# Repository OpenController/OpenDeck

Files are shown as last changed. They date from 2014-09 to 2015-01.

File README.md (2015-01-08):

# OpenDeck Platform

OpenDeck MIDI platform is a combination of microcontroller firmware, PCB board and GUI application.
The platform allows hassle-free building of MIDI controllers and their configuration via MIDI System Exclusive messages,
without any need of reprogramming the chip.

This repository contains MCU code, part list, schematic (circuit and PCB) and pre-compiled binaries, available for serial
baud rates: 38400, for use with virtual MIDI cable software and serial-to-midi converter, and 31250 for use with native
MIDI.

Code base is built upon OpenDeck library, Ownduino library (minimal fork of Arduino core library)
and modified Arduino MIDI library 3.2. All code is available under GNU GPL v3 licence.

# Configurable features

## Hardware parameters

* Board type (OpenDeck reference board, Tannin board, or user-defineable board in `HardwareControl.cpp`)
* Enable/disable buttons
* Enable/disable LEDs
* Enable/disable potentiometers

## Features

### MIDI features

* Enable/disable standard note off

### Button features

* Enable/disable long-press mode

### LED features

* Enable/disable start-up routine
* Enable/disable blinking

### Potentiometer features

* Enable/disable potentiometer notes

### MIDI channels

* Button note channel
* Long-press button note channel
* Program change button channel
* Potentiometer CC channel
* Potentiometer program change channel
* Potentiometer note channel
* Input MIDI channel

## Button configuration

* Hardware parameters: long-press time
* Button type (momentary/latching)
* Enable/disable program change send instead of notes
* Button MIDI note

## Potentiometer configuration

* Hardware parameters: (reserved/no parameters yet)
* Enable/disable potentiometer
* Enable/disable program change send instead of CC
* Invert potentiometer
* CC/Program change number
* Lower CC/PP limit
* Upper CC/PP limit

## LED configuration

* Hardware parameters: total LED number, blink time, start-up switch time, start-up routine
* LED activation note
* LED start-up number
* Test LED state (constant on/off, blink on/off)

## Data restoration

* Restoration of single parameter back to default (ie. restore potentiometer 6 CC number to default)
* Restoration of all parameters within message type (ie. restore all button notes to default)
* Complete factory reset of all values

# SysEx configuration

All configuration is done using MIDI System Exclusive messages.
Before attempting to change parameters of OpenDeck controller, a "Hello World" message must be sent to controller:

F0 00 53 43 F7

F0 is a SysEx start, 00, 50 and 43 are ID bytes, and F7 is SysEx end. After the controller receives the message, it
enables full manipulation using SysEx protocol, and responds with the same message, with an extra ACK byte at the end, 0x41:

F0 00 53 43 41 F7

After that, board type must be specified. When using OpenDeck reference board, set it using the following message:

F0 00 53 43 01 00 00 00 00 01 F7

Each SysEx message (except for hello world) uses the same format:

F0 ID ID ID WISH AMOUNT MESSAGE_TYPE MESSAGE_SUBTYPE PARAMETER_ID NEW_PARAMETER_ID F7

## ID

* Byte 1: 0x00
* Byte 2: 0x53
* Byte 3: 0x43

## WISH

* Get (0x00)
Used to request data from the controller
* Set (0x01)
Changing parameters
* Restore (0x02)
Data restoration to default state

## AMOUNT
* Single (0x00)
Only one parameter
* All (0x01)
All parameters

### MESSAGE_TYPE
There's a total of 7 message types available.

* Hardware configuration (0x00)
* Features (0x01)
* MIDI channel (0x02)
* Button (0x03)
* Potentiometer (0x04)
* LED (0x05)
* All (0x07)

### MESSAGE_SUBTYPE

Features, buttons, potentiometers, LEDs are the only types of message which have a sub-type. When dealing
with other message types, code 0x00 must be specified as sub-type.

Features:

* MIDI features (0x00)
* Button features (0x01)
* LED features (0x02)
* Potentiometer features (0x03)

Buttons:
* Hardware parameter (0x00)
* Type (0x01)
* Program change enabled (0x02)
* Button note (0x03)

Potentiometers:
* Hardware parameter (0x00)
* Pot enabled (0x01)
* Program change enabled (0x02)
* Pot inverted (0x03)
* CC/PP number (0x04)
* Lower CC/PP limit (0x05)
* Upper CC/PP limit (0x06)

LEDs:
* Hardware parameter (0x00)
* Activation note (0x01)
* Start-up number (0x02)
* State (0x03)

For more information, see examples in /examples folder.

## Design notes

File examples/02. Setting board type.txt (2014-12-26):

Controller doesn't work until board type has been specified.

For OpenDeck reference board, board type is 01:
F0 00 53 43 01 00 00 00 00 01 F7

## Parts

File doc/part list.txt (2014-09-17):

# OpenDeck reference board:

1x  reference PCB
1x  Arduino Pro Mini
1x  ULN2803 Darlington transistor array
1x  74HC238 decoder
2x  4051 analogue multiplexer
4x  220 Ohm resistors
32x 1N4148 diodes
1x  10µF electrolytic cap
5x  0.1µF capacitors

# USB MIDI board

1x  USB MIDI PCB
1x  Altmustech AU-123 Integrated USB MIDI Controller
1x  USB B female connector
1x  10µF electrolytic cap
1x  0.1µF cap
1x  0.01µF cap
2x  22p caps
2x  3mm LEDs
2x  330 Ohm resistors
1x  2k2 Ohm resistor
1x  1kOhm resistor
1x  12Mhz crystal
1x  2n2222 transistor

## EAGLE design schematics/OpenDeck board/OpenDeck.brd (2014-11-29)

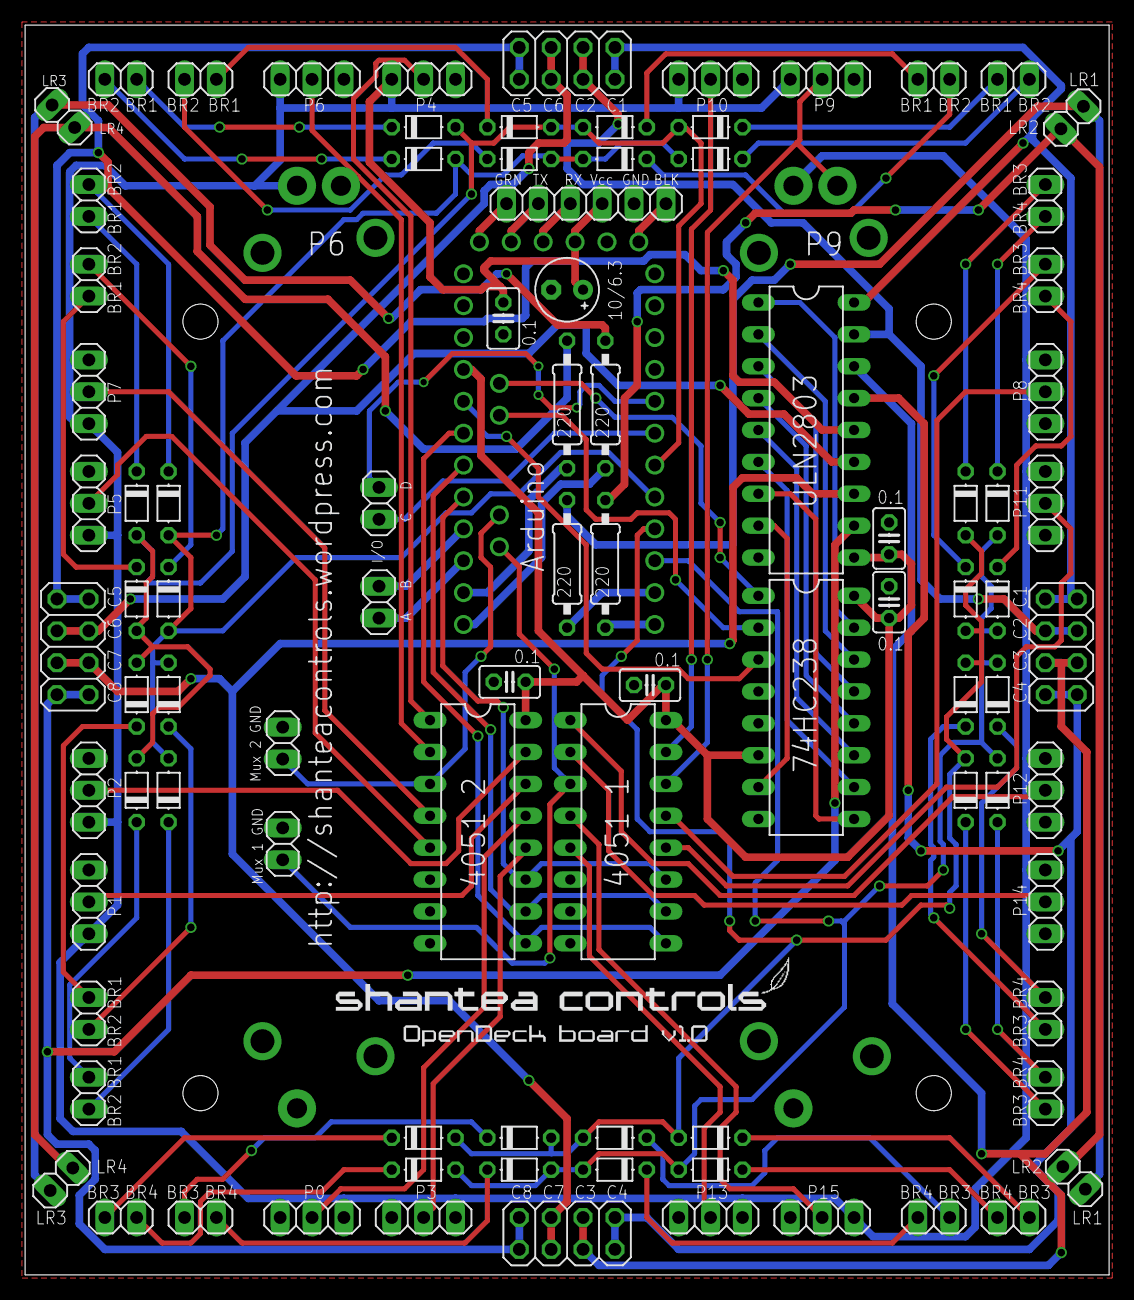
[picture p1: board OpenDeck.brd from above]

Board: 2 copper layers, 86.4 x 99.6 mm, 92 parts (1 on the bottom side), 95 nets.

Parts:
E$1: ARDUINO_PRO_MINI
E$2, E$3, E$7, E$11, E$14, E$18, E$22, E$35, E$41, E$42, E$43, E$46, E$47, E$62, E$64, E$73, E$74, E$82, E$87, E$88, E$94, E$95, E$96, E$97: 1X02
E$4, E$32, E$33, E$81: 0207/10
E$5: E2,5-5
E$6, E$9, E$20, E$63: 2X04
E$8, E$48, E$51, E$52, E$53, E$54, E$59, E$60, E$61, E$75, E$76, E$77, E$78, E$98, E$100, E$101: 1X03
E$10, E$12, E$16, E$17, E$19, E$21, E$23, E$24, E$25, E$26, E$27, E$28, E$29, E$30, E$31, E$34, E$36, E$37, E$38, E$39, E$40, E$44, E$45, E$65, E$66, E$67, E$68, E$69, E$70, E$71, E$72, E$92: D-5
E$13, E$49, E$84: DIL16
E$15, E$50, E$85, E$86, E$89: C025-025X050
E$80: DIL18
E$83: 1X06

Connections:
B_ROW_1: E$1.7, E$12.A, E$17.A, E$21.A, E$24.A, E$66.A, E$68.A, E$70.A, E$72.A
B_ROW_2: E$1.8, E$10.A, E$16.A, E$19.A, E$23.A, E$65.A, E$67.A, E$69.A, E$71.A
B_ROW_3: E$1.9, E$27.A, E$28.A, E$30.A, E$34.A, E$38.A, E$39.A, E$44.A, E$92.A
B_ROW_4: E$1.10, E$25.A, E$26.A, E$29.A, E$31.A, E$36.A, E$37.A, E$40.A, E$45.A
COLUMN_1: E$9.7, E$9.8, E$20.7, E$20.8, E$80.18
COLUMN_2: E$9.5, E$9.6, E$20.5, E$20.6, E$80.17
COLUMN_3: E$6.5, E$6.6, E$9.3, E$9.4, E$80.16
COLUMN_4: E$6.7, E$6.8, E$9.1, E$9.2, E$80.15
COLUMN_5: E$20.1, E$20.2, E$63.7, E$63.8, E$80.14
COLUMN_6: E$20.3, E$20.4, E$63.5, E$63.6, E$80.13
COLUMN_7: E$6.3, E$6.4, E$63.3, E$63.4, E$80.12
COLUMN_8: E$6.1, E$6.2, E$63.1, E$63.2, E$80.11
DEC_0: E$1.A5, E$84.1
DEC_1: E$1.A4, E$84.2
DEC_2: E$1.20, E$84.3
DEC_OUT_0: E$80.1, E$84.15
DEC_OUT_1: E$80.2, E$84.14
DEC_OUT_2: E$80.3, E$84.13
DEC_OUT_3: E$80.4, E$84.12
DEC_OUT_4: E$80.5, E$84.11
DEC_OUT_5: E$80.6, E$84.10
DEC_OUT_6: E$80.7, E$84.9
DEC_OUT_7: E$80.8, E$84.7
GND: E$1.4, E$1.23, E$1.GND, E$5.-, E$8.3, E$13.6, E$13.7, E$13.8, E$15.2, E$48.1, E$49.6, E$49.7, E$49.8, E$50.2, E$51.1, E$52.1, E$53.1, E$54.1, E$59.1, E$60.1, E$61.1, E$75.1, E$76.1, E$77.1, E$78.1, E$80.9, E$83.5, E$84.4, E$84.5, E$84.8, E$85.1, E$86.1, E$87.2, E$88.2, E$89.2, E$98.3, E$100.3, E$101.3
LED_ROW_1: E$18.1, E$33.2, E$82.1
LED_ROW_2: E$18.2, E$32.2, E$82.2
LED_ROW_3: E$4.2, E$22.2, E$41.2
LED_ROW_4: E$22.1, E$41.1, E$81.2
MUX_1_OUT: E$1.A7, E$49.3, E$88.1
MUX_2_OUT: E$1.A6, E$13.3, E$87.1
P0A: E$48.2, E$49.13
P1: E$13.13, E$101.2
P1A: E$49.14, E$54.2
P2: E$13.14, E$75.2
P2A: E$49.15, E$53.2
P3: E$13.15, E$76.2
P3A: E$49.12, E$59.2
P4: E$13.12, E$100.2
P4A: E$49.1, E$77.2
P5: E$8.2, E$13.1
P5A: E$49.5, E$52.2
P6: E$13.5, E$60.2
P6A: E$49.2, E$78.2
P7: E$13.2, E$98.2
P7A: E$49.4, E$51.2
P8: E$13.4, E$61.2
S0: E$1.17, E$13.11, E$49.11
S1: E$1.18, E$13.10, E$49.10
S2: E$1.19, E$13.9, E$49.9
S$1: E$1.15, E$43.1
S$2: E$1.16, E$43.2
S$3: E$1.5, E$42.2
S$4: E$1.6, E$42.1
S$6: E$39.C, E$95.2
S$7: E$25.C, E$96.2
S$10: E$38.C, E$94.2
S$11: E$1.11, E$33.1
S$12: E$26.C, E$97.2
S$14: E$1.12, E$32.1
S$16: E$1.13, E$4.1
S$19: E$1.14, E$81.1
S$22: E$1.GRN, E$83.1
S$23: E$1.TXO, E$83.2
S$24: E$1.RXI, E$83.3
S$28: E$1.BLK, E$83.6
S$52: E$2.1, E$31.C
S$53: E$2.2, E$30.C
S$54: E$11.1, E$29.C
S$55: E$11.2, E$28.C
S$56: E$36.C, E$47.2
S$57: E$34.C, E$47.1
S$58: E$45.C, E$46.2
S$59: E$44.C, E$46.1
S$60: E$12.C, E$35.1
S$61: E$10.C, E$35.2
S$62: E$3.2, E$24.C
S$63: E$3.1, E$23.C
S$64: E$14.2, E$21.C
S$65: E$14.1, E$19.C
S$66: E$7.2, E$16.C
S$67: E$7.1, E$17.C
S$69: E$92.C, E$96.1
S$70: E$40.C, E$95.1
S$73: E$27.C, E$97.1
S$74: E$37.C, E$94.1
S$76: E$71.C, E$73.1
S$77: E$72.C, E$73.2
S$78: E$64.2, E$65.C
S$79: E$64.1, E$66.C
S$80: E$70.C, E$74.2
S$81: E$69.C, E$74.1
S$82: E$62.1, E$68.C
S$83: E$62.2, E$67.C
VCCA: E$1.VCC, E$5.+, E$8.1, E$48.3, E$51.3, E$52.3, E$53.3, E$54.3, E$59.3, E$60.3, E$61.3, E$75.3, E$76.3, E$77.3, E$78.3, E$83.4, E$89.1, E$98.1, E$100.1, E$101.1
VCCD: E$1.21, E$13.16, E$15.1, E$49.16, E$50.1, E$80.10, E$84.6, E$84.16, E$85.2, E$86.2

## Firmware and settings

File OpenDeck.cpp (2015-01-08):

/*

OpenDeck platform firmware v1.3
Last revision date: 2014-12-25
Author: Igor Petrovic

*/

#include "OpenDeck.h"
#include "MIDI.h"
#include "Ownduino.h"
//#include "Encoder.h"
#include <avr/eeprom.h>


//velocity for on and off events
#define MIDI_NOTE_ON_VELOCITY   127
#define MIDI_NOTE_OFF_VELOCITY  0

//Encoder encoder1 = Encoder(PIN_C,PIN_D);


//MIDI callback handlers

void getNoteOnData(uint8_t channel, uint8_t note, uint8_t velocity)  {

    openDeck.storeReceivedNoteOn(channel, note, velocity);

}

void getSysExData(uint8_t *sysExArray, uint8_t size)    {

    openDeck.processSysEx(sysExArray, size);

}


//OpenDeck callback handlers

void sendButtonNotes(uint8_t buttonNote, bool buttonState, uint8_t channel)    {

    switch (buttonState) {

        case false:
        //button released
        if (openDeck.standardNoteOffEnabled())  MIDI.sendNoteOff(buttonNote, MIDI_NOTE_OFF_VELOCITY, channel);
        else                                    MIDI.sendNoteOn(buttonNote, MIDI_NOTE_OFF_VELOCITY, channel);
        break;

        case true:
        //button pressed
        MIDI.sendNoteOn(buttonNote, MIDI_NOTE_ON_VELOCITY, channel);
        break;

    }

}

void sendButtonPP(uint8_t channel, uint8_t program)    {

    MIDI.sendProgramChange(program, channel);

}

void sendPotCCData(uint8_t ccNumber, uint8_t ccValue, uint8_t channel) {

    MIDI.sendControlChange(ccNumber, ccValue, channel);

}

void sendPotNoteOnData(uint8_t note, uint8_t channel)    {

    MIDI.sendNoteOn(note, MIDI_NOTE_ON_VELOCITY, channel);

}

void sendPotNoteOffData(uint8_t note, uint8_t channel)   {

    if (openDeck.standardNoteOffEnabled())  MIDI.sendNoteOff(note, MIDI_NOTE_OFF_VELOCITY, channel);
    else                                    MIDI.sendNoteOn(note, MIDI_NOTE_OFF_VELOCITY, channel);

}

void sendSysExData(uint8_t *sysExArray, uint8_t size)   {

    MIDI.sendSysEx(size, sysExArray, false);

}


//configure opendeck library
void setOpenDeckHandlers()  {

    openDeck.setHandleButtonNoteSend(sendButtonNotes);
    openDeck.setHandleButtonPPSend(sendButtonPP);

    openDeck.setHandlePotCC(sendPotCCData);
    openDeck.setHandlePotNoteOn(sendPotNoteOnData);
    openDeck.setHandlePotNoteOff(sendPotNoteOffData);

    openDeck.setHandleSysExSend(sendSysExData);

}

//set MIDI handlers
void setMIDIhandlers()  {

    MIDI.setHandleNoteOn(getNoteOnData);
    MIDI.setHandleSystemExclusive(getSysExData);

}


//main
void setup()  {

    openDeck.init();

    setOpenDeckHandlers();
    setMIDIhandlers();

    //read incoming MIDI messages on specified channel
    //disable running status by default
    MIDI.begin(openDeck.getInputMIDIchannel());

    Serial.begin(38400);

}

void loop() {

    //process buttons and LEDs
    openDeck.processMatrix();

    //constantly check for incoming MIDI messages
    MIDI.read();

    //check if there is any received note to process
    openDeck.checkReceivedNoteOn();

    //read pots one analogue input at the time
    openDeck.readPots();

    //openDeck.readEncoders(encoder1.read());

}

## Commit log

2014-09-10 lots of changes
    * remodeled sysex response function - much simpler now
    * buttons and pots are now fully configurable via sysex
    * remodeled LED code - constant and blink state are now handled via same
    note, only with different velocity (0-62 constant, 63-127 blink)
    * seprated led notes (MIDI activation notes) and led numbers (only used
    for start-up)
    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
    [AU123_rev2.brd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]
2014-09-11 enable led control via sysex, other
    * LEDs are now fully configurable via sysex
    * added more start-up routine patterns
    * enableAanalogueInput now returns true for valid and false for invalid
    argument
    * blinkMode checking is now done in handleLED to enable blink control
    via sysex
    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
2014-09-12 add opendeck board and gerber files
    [OpenDeck.brd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]
2014-09-15 prepare for 1.0 release
    * each code category is now placed inside its own .cpp file
    * added support for configuring free pins via sysex
    * get/set commands for start-up routine pattern and start-up switch time
    now call startUpRoutine, to preview current/updated state of routine
    * fixed bug which caused wrong checking of new parameters for set all
    command
    * modified MIDI library - for details see MIDI.cpp or MIDI.h
    * re-organised default values in PROGMEM
    * misc
    [OpenDeck.cpp]
2014-09-24 defineable pot range, optimizations
    * pots now have defineable range using sysex (ie. 40-120 instead of
    0-127)
    * MIDI_SYSEX_ARRAY_SIZE is now 144 instead of 255 to reduce memory usage
    * removed eepromAddress variable from EEPROM.cpp functions
    * reduce number of pots in EEPROM from 128 to 64
    * some initial encoder support work
    * move most of defines from SysEx.h to enums for easier manipulation
    * remove Tannin.cpp (added by mistake)
2014-09-24 examples
    * add examples for controller configuration
    * fix start-up routine switch time upper limit
    * bump version to 1.1
    * update pre-compiled binaries
    [OpenDeck.cpp]
2014-09-27 bug fixing
    * fix wrongly initialised message start bytes
    * remove sendButtonDataCallback from LEDs.cpp (debug leftover)
2014-09-27 LED start up number range fix
    * don't allow setting stat-up number to LED if number is bigger or equal
    to total number of LEDs
2014-09-27 more examples
    * add examples for hardware features
    * add examples for LED start-up numbers
    * reorganized list
2014-11-02 more work toward encoder support
    *added more encoder code
    *button debouncing should now be much faster, as the algorithm now
    debounces entire column at once instead of each button individually
    *faster mux read code
2014-11-02 fix column switch code (column was always zero)
2014-11-05 fix reversed column switching
    * columns now match writing on PCB board
    * remove NOP from readMux and place it into setMuxOutput instead
    * move column debouncing into separate function
2014-11-05 optimise analog reading code
    * readPots function now reads first half of data from mux on first pass,
    and second half on second pass, to avoid slowing down of column
    switching in matrix
2014-11-05 remove NOP from mux switch code
    * reasoning: NOP isn't actually necessary since code doesn't read analog
    values immediately after mux input selection
2014-11-18 many performance improvements
    * free pin configuration has been removed due to unnecessary processing
    * encoder support commented out until it's ready
    * column and analogue pin switching now occur using TIMER2
    * replace default LED activation notes and LED start-up numbers with
    impossible values to avoid issues
    * hardware control functions now have inline keyword to gain some
    performance
    * code is now compiled using latest Ownduino 1.0
    [OpenDeck.cpp]
2014-11-18 remove mention of free pin configuration
2014-11-18 remove free pin mention
2014-11-19 change default LED start up and activation notes
    * change default LED start up and activation notes to avoid issues with
    SysEx
    * changed sysExSetLEDstartNumber function
2014-11-21 fixed start-up animation, misc
    * fixed broken start-up routine - it now makes use of interrupted matrix
    switching
    * rename adcConnected to getMuxPin, for clarity
    * simpler initial pot reading function
    * calculate potNumber using function
2014-11-29 fix potentiometer numbers on PCB
    [OpenDeck.brd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]
2014-11-29 disable running status by default
    * disable running status by default due to issues when using USB MIDI
    board
    [OpenDeck.cpp]
2014-12-02 optimisations
    * ADC is now configured to read 8 bit values
    * disable digital io on used analog pins
    * remove potTimer
2014-12-26 prepare for v2.0
    * added support for program change in MIDI lib
    * buttons can be configured to send program change instead of notes
    * restructured EEPROM data
    * move initVariables out of constructor
    * move more init functions to initBoard
    * restructured SysEx protocol
    * updated readme
    * remove USB MIDI PCB as it doesn't support SysEx
    * remove old examples
    [AU123_rev2.brd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]
2014-12-26 don't allow same values for led activation/startup
    * throw new parameter error when trying to set same led activation note
    or start-up number for multiple LEDs
    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
    [OpenDeck.cpp]
2015-01-08 remove running status mentions, misc
    * remove running status parameter from EEPROM
    * remove runningStatusEnabled function
    * disable switching of mux pins during sysex message processing
    * fix bugs in SysEx protocol
    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

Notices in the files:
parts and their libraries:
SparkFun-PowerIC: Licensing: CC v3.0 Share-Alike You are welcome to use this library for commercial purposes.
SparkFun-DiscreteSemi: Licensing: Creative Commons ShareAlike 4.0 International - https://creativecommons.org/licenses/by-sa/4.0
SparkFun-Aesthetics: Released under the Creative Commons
